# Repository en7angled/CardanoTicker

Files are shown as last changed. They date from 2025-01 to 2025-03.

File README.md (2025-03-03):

# CardanoTicker

CardanoTicker is an open-source DIY project designed to provide real-time insights into the Cardano blockchain. It features a customizable, user-friendly dashboard with a 3D-printed case for assembly, making it an accessible solution for blockchain enthusiasts and developers alike.

## Project Overview

The CardanoTicker project is a part of Project Catalyst, aiming to explore new use cases for the Cardano ecosystem. With a focus on modularity and accessibility.

## Features

- **Open Source**: Fully customizable; contributions are welcome via GitHub.
- **Flexible Design**: Supports various display configurations, including static and dynamic displays.
- **Low-Power Option**: Alternative build using ESP32/Raspberry Pi Pico for energy-efficient operation.
- **Customizable Dashboards**: Three pre-configured dashboards for price, blockchain, and node data.

## Getting Started

Follow these steps to assemble and configure your CardanoTicker:

### 1. Hardware Components

Refer to the [Hardware Components List](https://github.com/en7angled/CardanoTicker/blob/main/m1/hardware_components_list.md) for detailed sourcing options. All components are listed with suppliers, costs, and compatibility information.

### 2. Software Setup

Clone the repository and follow the Setup Guide to configure the software:
- [Connected Version (raspberry pi)](https://github.com/en7angled/CardanoTicker/blob/main/docs/installation_guide_raspberry_pi.md) 
- [Wireless Version (esp32)](https://github.com/en7angled/CardanoTicker/blob/main/docs/installation_guide_esp32.md) 

### 3. System Components Overview

Refer to the [System Components](https://github.com/en7angled/CardanoTicker/blob/main/docs/System_Components.md) for the system design details

### 4. 3D Case Printing

Download the STL files from the [Printables link](https://www.printables.com/model/1145410-4-inch-display-case). Ensure you have access to a 3D printer and follow the printing instructions for optimal results.

## Screenshots


## Contribution Guidelines

We welcome contributions from the community! Here’s how you can contribute:

1. Report bugs or suggest features via [GitHub Issues](https://github.com/en7angled/CardanoTicker/issues).
2. Discuss ideas in the [GitHub Discussions](https://github.com/en7angled/CardanoTicker/discussions/).
3. Submit pull requests (PRs) that align with the project’s goals.

### Future Milestones

- Improved software functionality.
- Enhanced case designs.
- Expanded dashboard capabilities.

## Feedback and Support

Your feedback is invaluable! Use the following channels for support or feedback:

- **GitHub Issues**: [Report Bugs](https://github.com/en7angled/CardanoTicker/issues)
- **Community Discussions**: [Join the Conversation](https://github.com/en7angled/CardanoTicker/discussions/)

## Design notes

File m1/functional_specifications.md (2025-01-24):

# Functional Specifications for Cardano Ticker Project

---

## 1. Overview
The Cardano Ticker project provides a compact, DIY cryptocurrency tracking device displaying real-time data on the Cardano blockchain. It combines low-cost hardware with an easy-to-assemble 3D-printed case and intuitive software dashboards for monitoring critical metrics.

---

## 2. Key Features
1. **Dynamic Data Display:**
   - Real-time price updates for ADA (Cardano).
   - Network statistics, including staking metrics and node status.
   - Blockchain synchronization progress.

2. **Multiple Display Options:**
   - Static e-paper display for low-power builds.
   - Dynamic LCD display for higher refresh rates.

3. **Wireless Connectivity:**
   - Wi-Fi-enabled updates for data fetching.
   - Optional battery-powered operation for portable setups.

4. **Open-Source and Expandable:**
   - Hosted on GitHub with community contributions encouraged.
   - Flexible software framework allowing feature expansions.

---

## 3. Hardware Requirements
1. **Raspberry Pi Zero 2W or ESP32 (alternative low-power version)**
2. **Display Modules:**
   - E-paper (Waveshare 4.01-inch) or LCD display.
3. **Power Options:**
   - USB charger for non-portable versions.
   - Battery pack for portable versions.
4. **3D-printed Case:**
   - Snap-fit or sliding mechanism for easy assembly.
   - Compatible with common 3D printer formats (STL, OBJ).
5. **MicroSD card**
   - only required for non-portable standalone version
8. **Buttons and Sensors (Optional):**
   - For user interactions or future extensions.

---

## 4. Software Functionalities
### 4.1 Data Fetching Module
- Periodically fetches data from Cardano blockchain APIs.
- Includes caching to handle network interruptions.

### 4.2 Display Management Module
- Dynamically updates screens based on the selected display type.
- Allows switching between dashboards (price, node, blockchain).

### 4.3 Configuration Module
- Provides initial setup through a web interface or USB configuration file.
- Allows customization of update intervals and data sources.

### 4.4 Dashboard Mock-ups
#### 1. Price Information Dashboard:
- Displays current ADA price in multiple currencies.
- Includes percentage change and price trends.

#### 2. Blockchain Dashboard:
- Shows network status, slot height, and block progress.
- Displays epoch and slot details.

#### 3. Node Dashboard:
- Provides node synchronization status.
- Displays peer connections and uptime.

---

## 5. Data Sources
- **API Integrations:**
  - BlockFrostApi or CryptoCompare for price updates.
  - BlockFrostApi, Cardano Explorer APIs for network statistics.
  - Easy to integrate other API providers and data sources
- **Fallback Mechanisms:**
  - Local cache for offline scenarios.
---

## 6. Compatibility
- **Operating System Support:**
  - Raspberry Pi OS (Lite or Full).
  - ESP-IDF (for ESP32 builds).
- **File Formats:**
  - STL, OBJ, 3MF for 3D printing.
- **Connectivity:**
  - Wi-Fi or USB for updates.

---

## 7. Testing and Validation
- **Hardware Tests:**
  - Fit and alignment of 3D-printed components.
  - Functionality tests for all hardware modules.
- **Software Tests:**
  - API response validation.
  - Display refresh tests.
---

## 8. User Feedback Mechanisms
1. GitHub Issues for reporting bugs.
2. Pull requests for community contributions.

---

## 9. Deployment and Delivery
- **GitHub Repository:**
  - Hosting code, documentation, and 3D files.
- **Thingiverse/Printables:**
  - STL files for 3D printing.
- **Documentation:**
  - Step-by-step assembly and configuration guides.

---

## 10. Future Roadmap
1. Integration with additional blockchains.
2. Enhanced data visualization tools.
3. Battery optimization for longer runtimes.

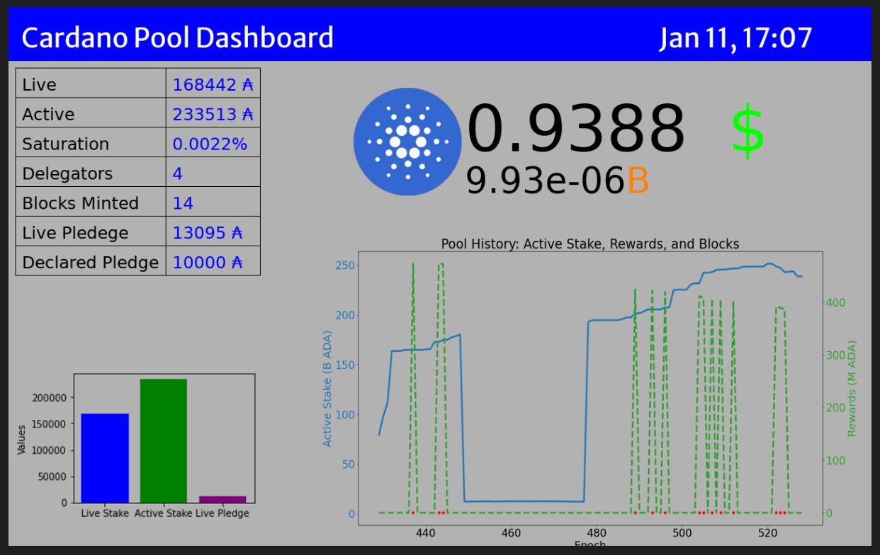
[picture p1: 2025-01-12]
m1/dashboard_mockups/pool_dashboard/pool_simple_with_price.jpeg

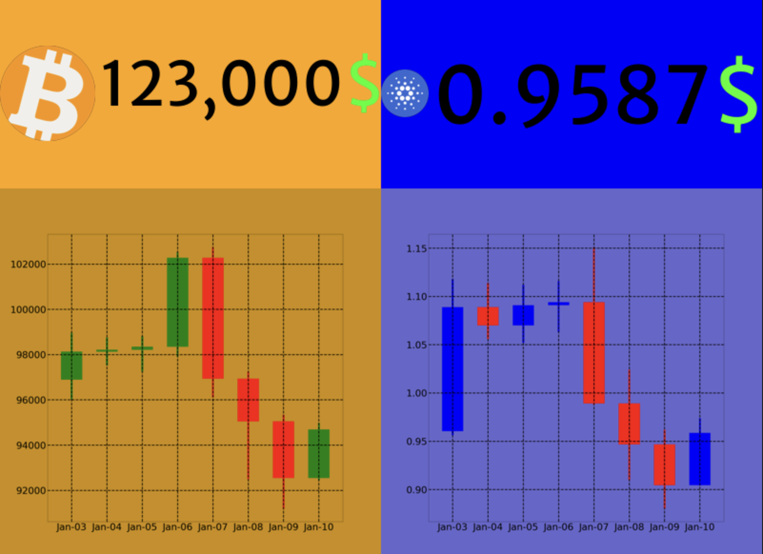
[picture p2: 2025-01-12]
m1/dashboard_mockups/price_dashboard/ada_btc_usd_live_chart.png

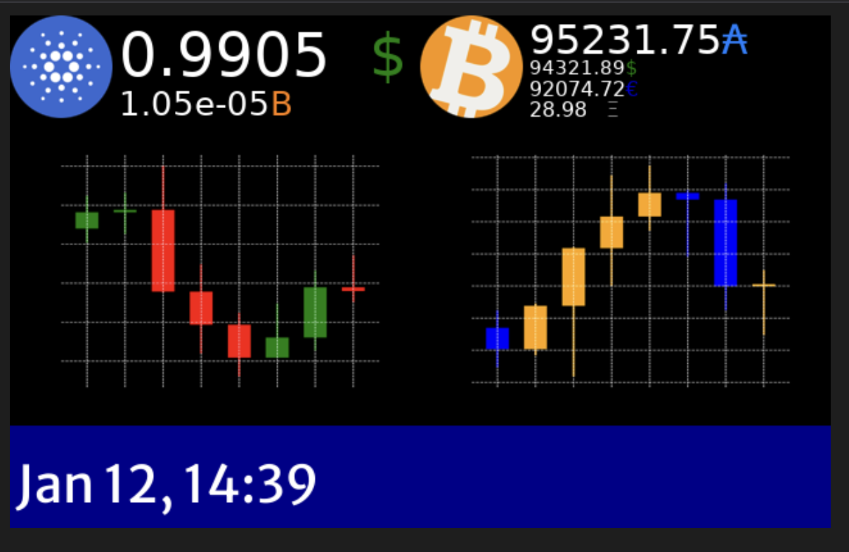
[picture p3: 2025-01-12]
m1/dashboard_mockups/price_dashboard/ada_btc_ticker_dark.png

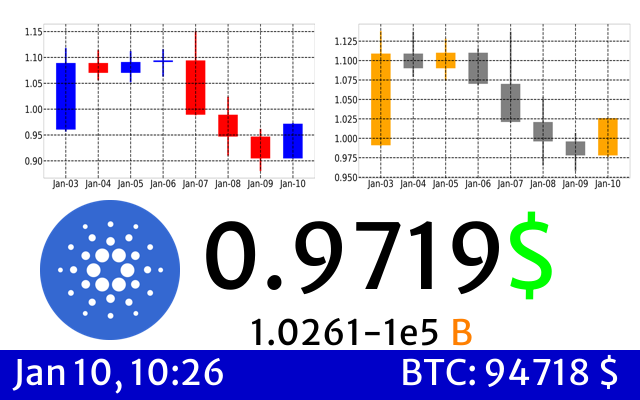
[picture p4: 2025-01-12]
m1/dashboard_mockups/price_dashboard/ada_btc_ticker.bmp

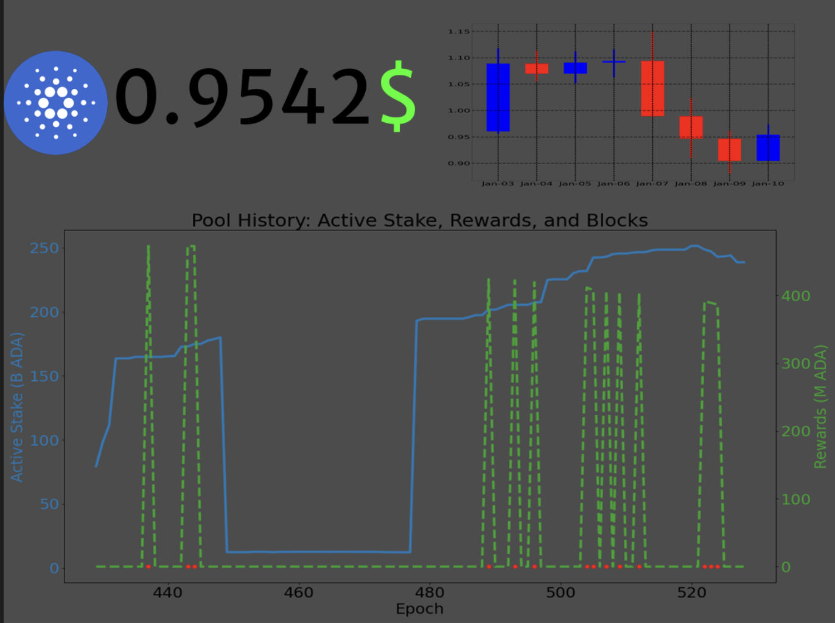
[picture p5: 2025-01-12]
m1/dashboard_mockups/pool_dashboard/pool_and_price_chart.png

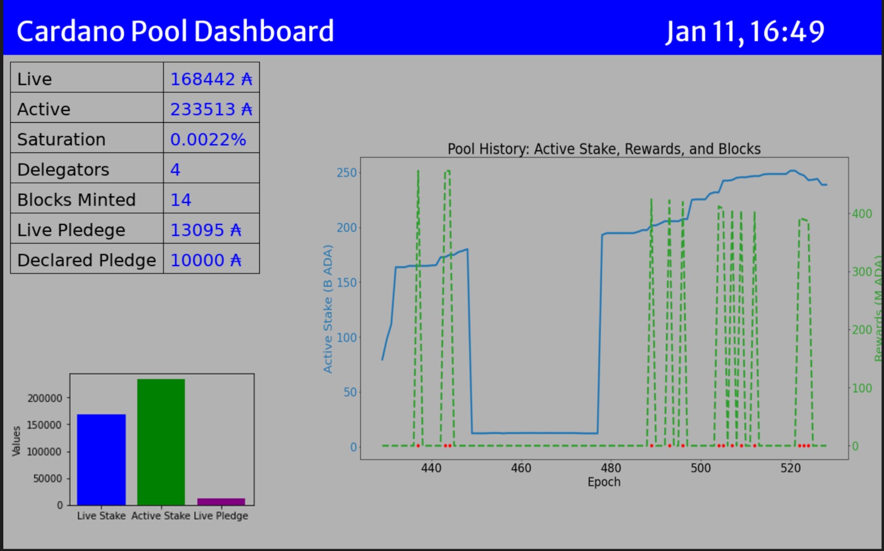
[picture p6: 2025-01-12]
m1/dashboard_mockups/pool_dashboard/pool_simple.jpeg

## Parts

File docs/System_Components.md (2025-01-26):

# CardanoTicker Software Components Architecture

## Overview
The **CardanoTicker** integrates hardware and software to display blockchain data on e-ink or LCD screens. Its architecture is designed for modularity, enabling dynamic updates and user interaction via buttons.

## Software Components

### 1. Config Manager
- **Role**: Manages and provides configuration settings.
- **Data Flow**: Interacts with other components to supply necessary configurations.

### 2. Data Fetcher
- **Role**: Fetches and processes data from blockchain APIs.
- **Data Flow**: Supplies parsed data to the Dashboard Generator.

### 3. Dashboard Generator
- **Role**: Combines data, configuration, and a dashboard description file to generate and update the final dashboard image.
- **Data Flow**:
  - Receives configuration from Config Manager.
  - Retrieves data from Data Fetcher.
  - Uses a dashboard description file containing widget types and layout positions to generate the final dashboard.

### 4. Display
- **Role**: Renders visual content for the user.
- **Data Flow**: Receives the final dashboard image from the Dashboard Generator.

### 5. Buttons
- **Role**: Provides interactivity via user input.
- **Data Flow**: Triggers actions in Config Manager and Dashboard Generator.

## Runners

The system operates with two primary runners to handle distinct tasks:

### 1. Provider
- **Purpose**: Acts as the backend service to fetch blockchain data, process it, and prepare it for display.
- **Responsibilities**:
  - Fetches data via APIs using the `Data Fetcher`.
  - Passes data to the `Dashboard Generator` for processing.
- **Execution**:
  - In connected versions, runs on the same device as the Displayer.
  - In wireless versions, runs on a separate machine on the same network.

### 2. Displayer
- **Purpose**: Manages the rendering and user-facing operations of the CardanoTicker.
- **Responsibilities**:
  - Utilizes the `Dashboard Generator` to create the final dashboard image.
  - Sends the image to the `Display` for rendering.
  - Handles user input from the `Buttons` to interact with dashboards.
- **Execution**:
  - Runs on the device connected to the e-ink or LCD display.

## Data Flow Diagram 
```mermaid
graph TD
    subgraph Provider
        ConfigManager[Config Manager] -->|Provides Config| DataFetcher[Data Fetcher]
        DataFetcher -->|Supplies Data| DashboardGenerator[Dashboard Generator]
        DashboardDescription[Dashboard Description File] -->|Defines Layout| DashboardGenerator
    end

    subgraph Displayer
        DashboardGenerator -->|Generates Final Image| Display[Display]
        Buttons -->|Triggers Actions| DashboardGenerator
    end
```

## Wireless vs Connected Architecture

### Connected Version
- Both the Provider and Displayer run on the same device.
- Suitable for setups using Raspberry Pi or similar hardware.

### Wireless Version
- The Provider runs on a separate machine (e.g., a server or PC) connected via the same network.
- The Displayer runs on the ESP32 or similar low-power device, fetching processed data from the Provider.

```mermaid
graph TD
    subgraph Wireless_Provider
        ConfigManager[Config Manager] -->|Provides Config| DataFetcher[Data Fetcher]
        DataFetcher -->|Supplies Data| DashboardGenerator[Dashboard Generator]
        DashboardDescription[Dashboard Description File] -->|Defines Layout| DashboardGenerator
        DashboardGenerator -->|Generates| Image[Final Image Frame]
    end

    subgraph Wireless_Displayer
        ESP32[ESP32 Device] -->|Fetches Image| Image
        ESP32 -->|Displays| Display[Display]
        ESP32 -->|Receives Input| Buttons
    end

    Wireless_Provider -->|Transfers Data| Wireless_Displayer
```

## Summary
The CardanoTicker architecture is modular and extensible, enabling easy updates, efficient data handling, and user-friendly interaction through a clear component flow. The two main runners, the Provider and the Displayer, ensure seamless backend and frontend operations. The `Dashboard Generator` plays a central role, utilizing a dashboard description file to define widget types and layout positions, ensuring flexibility and customization. For connected versions, both runners operate on the same device. In wireless versions, the Provider and Displayer communicate over the network, enhancing flexibility for distributed setups.

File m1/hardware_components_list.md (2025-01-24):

# Hardware Components List

## 1. Connected Static Display
**Description:** This build uses a Raspberry Pi Zero 2 W as the main controller and features a static e-paper display for low-power, high-visibility output. It connects directly to a power source and is ideal for setups that do not require wireless functionality.
| Component | Description | Estimated Cost (USD) | Sourcing Options | Notes |
|---|---|---|---|---|
| 3D Case (Custom Design) | Protective enclosure for hardware. | 0 | resources/case_models/waveshare_4.01| Custom-designed enclosure for the hardware components. Printable with standard 3D printers; files available in STL or OBJ format.  |
| GPIO Header | For connecting displays to the Raspberry Pi. | $1 - $2 | 1. [Adafruit](https://www.adafruit.com/product/3662)<br>2. [SparkFun](https://www.sparkfun.com/raspberry-pi-gpio-male-header-2x20.html)  <br>3. [Mouser Electronics](https://eu.mouser.com/ProductDetail/SparkFun/PRT-14275?qs=YCa/AAYMW01SLG/RsDUFug%3D%3D) | Required for connecting external devices like displays or sensors via GPIO pins. Preinstalled headers simplify setup, but unsoldered options allow custom configurations. Supports SPI, I2C, and UART communication protocols. |
| Push Button (x2) | Momentary push buttons for user interaction. | $1 - $3 each | 1. [Adafruit]( https://www.adafruit.com/product/1010)<br>2. [SparkFun](https://www.sparkfun.com/products/97)<br>3. [Amazon](https://www.amazon.com/DIYables-Button-Arduino-ESP8266-Raspberry/dp/B0BXKN4TY6) | SPST (Single Pole Single Throw) push buttons are recommended. Ensure 3.3V or 5V compatibility. |
| E-paper color display | E-paper slow refresh rate with color support | $30 - $40 | 1. [Waveshare](https://www.waveshare.com/4.01inch-e-paper-hat-f.htm)  <br>2. [Waveshare](https://www.waveshare.com/4inch-e-paper-hat-plus-e.htm)<br>3. [GoodDisplay](https://www.good-display.com/product/532.html)<br>4. [Spotpear](https://spotpear.com/shop/Raspberry-Pi-Jetson-Nano-Arduino-STM32-4-inch-e-Paper-Ink-Spectra-E6-600x400-Screen-Display/4inch-e-Paper-E.html) | Low-power e-paper display with colors. The refresh rate is ~15s which makes it suitable for updating the data once at ~30 minutes to avoid the chance of glazing at the ticker during the refresh. Compatible with both Raspberry Pi and ESP32 via SPI interface.|
| Raspberry Pi Zero 2 W | Single-board computer for running software components. | $15 | 1. [Raspberry Pi Official Store](https://www.raspberrypi.com/products/raspberry-pi-zero-2-w/)  <br>2. [Amazon](https://www.amazon.co.uk/Raspberry-Pi-Zero-2-W/dp/B09KLVX4RT)  <br>3. [The Pi Hut](https://thepihut.com/products/raspberry-pi-zero-2) | Compact single-board computer suitable for Linux-based systems. Supports GPIO interface for direct hardware connections. Requires a 5V/2.5A power supply for stable operation. Ensure GPIO header is preinstalled or solder it if necessary. Compatible with HDMI and SPI displays. |
| Micro SD Card (16GB or higher) | Storage for operating system and software. | $5 - $15 | [Amazon](https://www.amazon.de/-/en/Kingston-Industrial-microSD-microSDHC-Adapter/dp/B09CYDWS4J)<br>[Adafruit](https://www.adafruit.com/product/2693)<br>[Best Buy](https://www.bestbuy.com/site/sandisk-ultra-plus-32gb-microsdhc-uhs-i-memory-card/6346822.p?skuId=6346822) | Class 10 or higher recommended for faster performance. |
| **Total Estimated Cost** | | **$55 - $75** | | |

## 2. Connected Dynamic Display
**Description:** This build utilizes a Raspberry Pi Zero 2 W and a dynamic display, making it suitable for applications requiring faster refresh rates. It supports direct connections via HDMI, providing high-quality visuals and responsiveness. It is designed for users who need wired reliability and higher interactivity.

| Component | Description | Estimated Cost (USD) | Sourcing Options | Notes |
|---|---|---|---|---|
| 3D Case (Custom Design) | Protective enclosure for hardware. | 0 | resources/case_models/waveshare_4.01 | Custom-designed enclosure for the hardware components. Printable with standard 3D printers; files available in STL or OBJ format.  |
| GPIO Header | For connecting displays to the Raspberry Pi. | $1 - $2 | 1. [Adafruit](https://www.adafruit.com/product/3662)<br>2. [SparkFun](https://www.sparkfun.com/raspberry-pi-gpio-male-header-2x20.html)  <br>3. [Mouser Electronics](https://eu.mouser.com/ProductDetail/SparkFun/PRT-14275?qs=YCa/AAYMW01SLG/RsDUFug%3D%3D) | Required for connecting external devices like displays or sensors via GPIO pins. Preinstalled headers simplify setup, but unsoldered options allow custom configurations. Supports SPI, I2C, and UART communication protocols. |
| Push Button (x2) | Momentary push buttons for user interaction. | $1 - $3 each | 1. [Adafruit]( https://www.adafruit.com/product/1010)<br>2.[SparkFun](https://www.sparkfun.com/products/97)<br>3. [Amazon](https://www.amazon.com/DIYables-Button-Arduino-ESP8266-Raspberry/dp/B0BXKN4TY6) | SPST (Single Pole Single Throw) push buttons are recommended. Ensure 3.3V or 5V compatibility. |
| Charger and Cable (Optional) | Power adapter and USB cable for non-battery builds. | $5 - $10 | 1. [Raspberry Pi Store](https://www.raspberrypi.com/products/micro-usb-power-supply/)  <br>2. [Amazon](https://www.amazon.de/s?k=Charger+and+Cable&crid=2GIHABL4PKSZU)  <br>3. Local Electronics Stores | Micro USB power adapter providing 5V/2.5A output, suitable for Raspberry Pi Zero 2 W. Ensure compatibility with regional power sockets. USB cables should be high-quality to avoid voltage drops during operation. |
| Raspberry Pi Zero 2 W | Single-board computer for running software components. | $15 | 1. [Raspberry Pi Official Store](https://www.raspberrypi.com/products/raspberry-pi-zero-2-w/)  <br>2. [Amazon](https://www.amazon.co.uk/Raspberry-Pi-Zero-2-W/dp/B09KLVX4RT)  <br>3. [The Pi Hut](https://thepihut.com/products/raspberry-pi-zero-2) | Compact single-board computer suitable for Linux-based systems. Supports GPIO interface for direct hardware connections. Requires a 5V/2.5A power supply for stable operation. Ensure GPIO header is preinstalled or solder it if necessary. Compatible with HDMI and SPI displays. |
| Mini HDMI to HDMI Adapter | Adapter to connect Raspberry Pi Zero 2 W to LCD display via HDMI. | $5 - $10 | 1. [Amazon](https://www.amazon.de/-/en/VIEVRE-Adapter-Gold-Plated-1080p-Black-2-pieces-mini-HDMI/dp/B0CLZQFKB1) | Required for connecting Raspberry Pi Zero 2 W to HDMI-compatible LCD display. |
| Display Options |  E-paper / LCD screen | $20 - $60 | 1. Higher Refresh Rate E-paper (b&w, fast refresh)<br>[Good Display](https://www.good-display.com/product/613.html)<br>[Amazon UK](https://www.amazon.co.uk/Waveshare-HAT-Resolution-Electronic-Controller/dp/B075R4QY3L)<br>[Waveshare](https://www.waveshare.com/5.83inch-e-paper-hat.htm)<br> 2. LCD Screen (high resolution, dynamic display)<br>[Waveshare](https://www.waveshare.com](https://www.waveshare.com/product/displays/lcd-oled/lcd-oled-1/5inch-lcd-for-pi.htm))<br>[Amazon](https://www.amazon.com/HDMI-LCD-Resolution-Resistive-Screen/dp/B07P5H2315)<br> [Emag](https://www.emag.ro/display-pentru-raspberry-pi-waveshare-ips-4-800x480-cu-panou-tactil-4inchhdmilcdwaveshare12030/pd/D8MF35MBM/) |1. Faster e-paper display for dynamic content. Supports SPI; compatible with both Raspberry Pi and ESP32. This can be used for more dynamic content but by giving up colors <br> 2.HDMI-based high refresh rate display for detailed visuals. Compatible with Raspberry Pi using HDMI interface. Not directly compatible with ESP32 without an HDMI driver board, making it impractical for wireless builds. Touchscreen models may require extra drivers and calibration. |
| Micro SD Card (16GB or higher) | Storage for operating system and software. | $5 - $15 | [Amazon](https://www.amazon.de/-/en/Kingston-Industrial-microSD-microSDHC-Adapter/dp/B09CYDWS4J)<br>[Adafruit](https://www.adafruit.com/product/2693)<br>[Best Buy](https://www.bestbuy.com/site/sandisk-ultra-plus-32gb-microsdhc-uhs-i-memory-card/6346822.p?skuId=6346822) | Class 10 or higher recommended for faster performance. |
| **Total Estimated Cost** | | **$60 - $110** | | |

## 3. Wireless Static Display
**Description:** Focused on low-power usage, this build combines an ESP32 WiFi module with a static e-paper display, making it ideal for long runtime battery-powered setups. It is optimized for scenarios where updates are less frequent, offering energy efficiency while maintaining wireless functionality.

| Component | Description | Estimated Cost (USD) | Sourcing Options | Notes |
|---|---|---|---|---|
| 3D Case (Custom Design) | Protective enclosure for hardware. | 0 | resources/case_models/waveshare_4.01 | Custom-designed enclosure for the hardware components. Printable with standard 3D printers; files available in STL or OBJ format.  |
| GPIO Header | For connecting displays to the Raspberry Pi. | $1 - $2 | 1. [Adafruit](https://www.adafruit.com/product/3662)<br>2. [SparkFun](https://www.sparkfun.com/raspberry-pi-gpio-male-header-2x20.html)  <br>3. [Mouser Electronics](https://eu.mouser.com/ProductDetail/SparkFun/PRT-14275?qs=YCa/AAYMW01SLG/RsDUFug%3D%3D) | Required for connecting external devices like displays or sensors via GPIO pins. Preinstalled headers simplify setup, but unsoldered options allow custom configurations. Supports SPI, I2C, and UART communication protocols. |
| Push Button (x2) | Momentary push buttons for user interaction. | $1 - $3 each | 1. [Adafruit]( https://www.adafruit.com/product/1010)<br>2. [SparkFun](https://www.sparkfun.com/products/97)<br>3. [Amazon](https://www.amazon.com/DIYables-Button-Arduino-ESP8266-Raspberry/dp/B0BXKN4TY6) | SPST (Single Pole Single Throw) push buttons are recommended. Ensure 3.3V or 5V compatibility. |
| E-paper color display |  E-paper slow refresh rate with color support | $30 - $40 | 1. [Waveshare](https://www.waveshare.com/4.01inch-e-paper-hat-f.htm)  <br>2. [Waveshare](https://www.waveshare.com/4inch-e-paper-hat-plus-e.htm)<br>3. [GoodDisplay](https://www.good-display.com/product/532.html)<br>4. [Spotpear](https://spotpear.com/shop/Raspberry-Pi-Jetson-Nano-Arduino-STM32-4-inch-e-Paper-Ink-Spectra-E6-600x400-Screen-Display/4inch-e-Paper-E.html) | Low-power e-paper display with 7 colors. The refresh rate is ~15s which makes it suitable for updating the data once at ~30 minutes to avoid the chance of glazing at the ticker during the refresh. Compatible with both Raspberry Pi and ESP32 via SPI interface.|
| ESP32 WiFi Module | Low-power microcontroller for battery-powered versions. In this version the data fetching and rendering is done on an external server for minimising power consumption | $5 - $10 | 1. [SparkFun](https://www.sparkfun.com/sparkfun-thing-plus-esp32-s3.html) <br>2. [Amazon](https://www.amazon.co.uk/esp32-module/s?k=esp32+module)  <br>3. [RS Components](https://uk.rs-online.com/web/p/wi-fi-modules/1697594) | Low-power microcontroller with built-in Wi-Fi and Bluetooth. Supports SPI, I2C, UART, and PWM interfaces for peripherals. Can operate on 3.3V directly; no level shifters required. Recommended for wireless, battery-powered setups. Use deep sleep modes for power-efficient operation. |
| Battery  | Power supply for low-power ESP32 version. | $10 - $20 | 1. [Adafruit](https://www.adafruit.com/product/1566)  <br>2. [SparkFun](https://www.sparkfun.com/lithium-ion-battery-pack-10ah-3a-1a-usb-ports.html)  <br>3. Local Electronics Stores | Power supply for ESP32 builds. Li-ion or Li-Po batteries recommended; ensure proper voltage (3.7V or 5V). Consider adding a battery management system (BMS) for safety and charging support. Capacity depends on runtime needs—calculate based on device consumption. |
| **Total Estimated Cost** | | **$50 - $70** | | |

## 4. Wireless Dynamic Display
**Description:** Designed for portability and flexibility, this build uses an ESP32 WiFi module, enabling wireless operation. It features a dynamic display for higher refresh rates and supports both battery-powered and wired configurations. This build is well-suited for applications requiring real-time updates and mobility.

| Component | Description | Estimated Cost (USD) | Sourcing Options | Notes |
|---|---|---|---|---|
| 3D Case (Custom Design) | Protective enclosure for hardware. | 0 | resources/case_models/waveshare_4.01 | Custom-designed enclosure for the hardware components. Printable with standard 3D printers; files available in STL or OBJ format.  |
| GPIO Header | For connecting displays to the Raspberry Pi. | $1 - $2 | 1. [Adafruit](https://www.adafruit.com/product/3662)<br>2. [SparkFun](https://www.sparkfun.com/raspberry-pi-gpio-male-header-2x20.html)  <br>3. [Mouser Electronics](https://eu.mouser.com/ProductDetail/SparkFun/PRT-14275?qs=YCa/AAYMW01SLG/RsDUFug%3D%3D) | Required for connecting external devices like displays or sensors via GPIO pins. Preinstalled headers simplify setup, but unsoldered options allow custom configurations. Supports SPI, I2C, and UART communication protocols. |
| Push Button (x2) | Momentary push buttons for user interaction. | $1 - $3 each | 1. [Adafruit]( https://www.adafruit.com/product/1010)<br>2. [SparkFun](https://www.sparkfun.com/products/97)<br>3. [Amazon](https://www.amazon.com/DIYables-Button-Arduino-ESP8266-Raspberry/dp/B0BXKN4TY6) | SPST (Single Pole Single Throw) push buttons are recommended. Ensure 3.3V or 5V compatibility. |
| Charger and Cable (Optional) | Power adapter and USB cable for non-battery builds. | $5 - $10 | 1. [Raspberry Pi Store](https://www.raspberrypi.com/products/micro-usb-power-supply/)  <br>2. [Amazon](https://www.amazon.de/s?k=Charger+and+Cable&crid=2GIHABL4PKSZU)  <br>3. Local Electronics Stores | Micro USB power adapter providing 5V/2.5A output, suitable for Raspberry Pi Zero 2 W. Ensure compatibility with regional power sockets. USB cables should be high-quality to avoid voltage drops during operation. |
| ESP32 WiFi Module | Low-power microcontroller for battery-powered versions. In this version the data fetching and rendering is done on an external server for minimising power consumption | $5 - $10 | 1. [SparkFun](https://www.sparkfun.com/sparkfun-thing-plus-esp32-s3.html) <br>2. [Amazon](https://www.amazon.co.uk/esp32-module/s?k=esp32+module)  <br>3. [RS Components](https://uk.rs-online.com/web/p/wi-fi-modules/1697594) | Low-power microcontroller with built-in Wi-Fi and Bluetooth. Supports SPI, I2C, UART, and PWM interfaces for peripherals. Can operate on 3.3V directly; no level shifters required. Recommended for wireless, battery-powered setups. Use deep sleep modes for power-efficient operation. |
| Higher Refresh Rate E-paper | Faster e-paper display for dynamic content. Supports SPI; compatible with both Raspberry Pi and ESP32. This can be used for more dynamic content but by giving up colors | $40 - $60 | 1. [Good Display](https://www.good-display.com/product/386.html) <br>2. [Good Display](https://www.good-display.com/product/226.html) <br>3. [Amazon UK](https://www.amazon.co.uk/Waveshare-Module-Resolution-Electronic-Controller/dp/B074NR1SW2) <br> | Faster e-paper display ideal for dynamic content. Supports SPI interface and works with both Raspberry Pi and ESP32. Partial refresh improves update speed compared to standard e-paper displays. Library support includes GxEPD2 for ESP32 and Python libraries for Raspberry Pi. |
| Battery  | Power supply for low-power ESP32 version. | $10 - $20 | 1. [Adafruit](https://www.adafruit.com/product/1566)  <br>2. [SparkFun](https://www.sparkfun.com/lithium-ion-battery-pack-10ah-3a-1a-usb-ports.html)  <br>3. Local Electronics Stores | Power supply for ESP32 builds. Li-ion or Li-Po batteries recommended; ensure proper voltage (3.7V or 5V). Consider adding a battery management system (BMS) for safety and charging support. Capacity depends on runtime needs—calculate based on device consumption. |
| **Total Estimated Cost** | | **$65 - $110** | | |

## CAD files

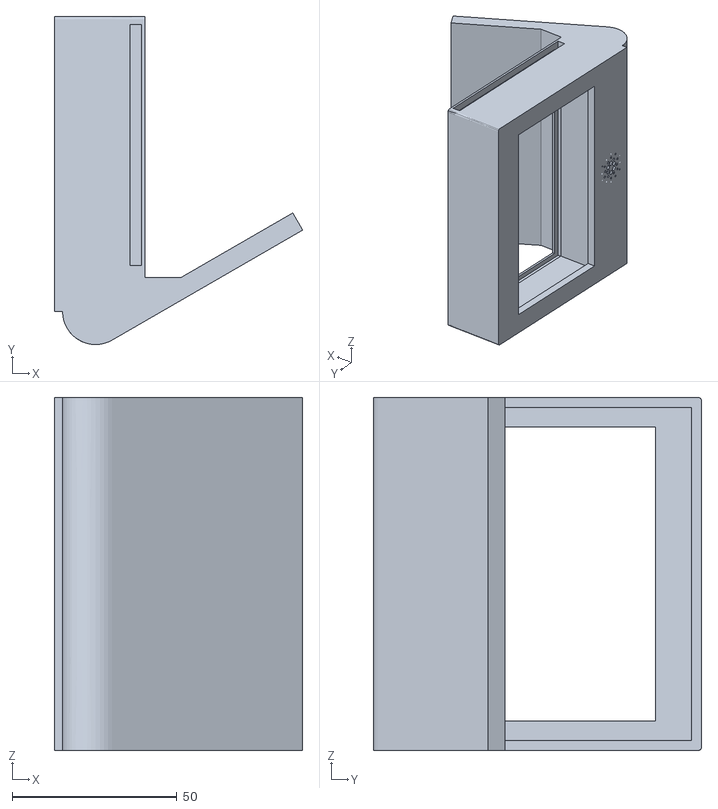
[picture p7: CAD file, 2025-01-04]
src/cardano_ticker/resources/case_models/waveshare_4.01/main_body.stl
75.3 x 99.5 x 107.0

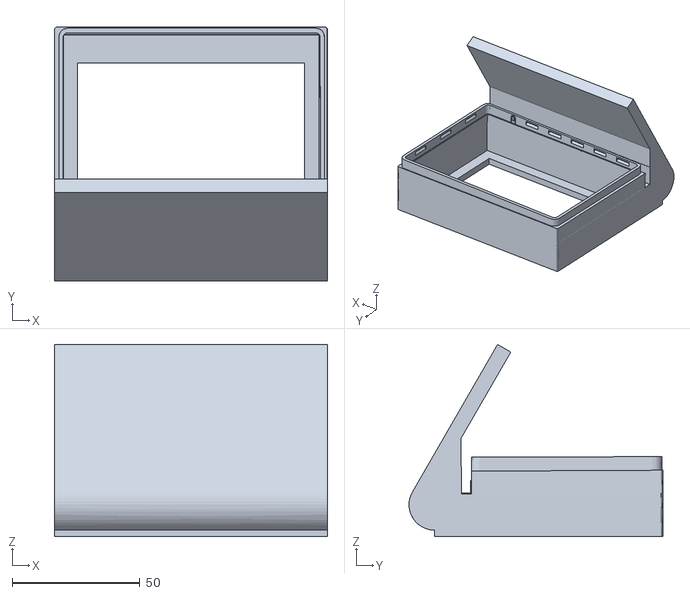
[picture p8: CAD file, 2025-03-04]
resources/case_models/waveshare_4.01/main_frame.stl
107.0 x 99.5 x 75.3

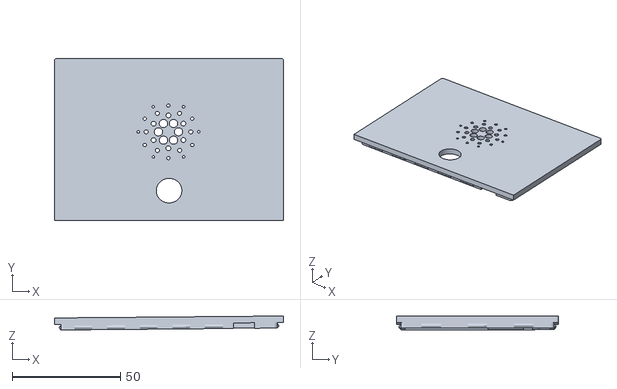
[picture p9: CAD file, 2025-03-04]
resources/case_models/waveshare_4.01/back_lid_v1.stl
106.0 x 75.0 x 6.49

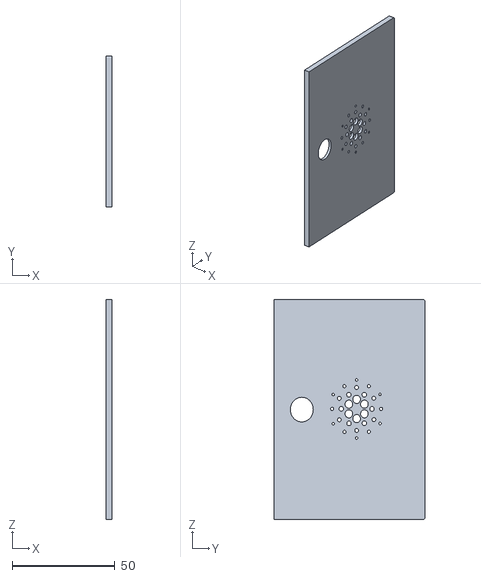
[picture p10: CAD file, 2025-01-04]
src/cardano_ticker/resources/case_models/waveshare_4.01/back_lid.stl
3.00 x 73.5 x 107.0

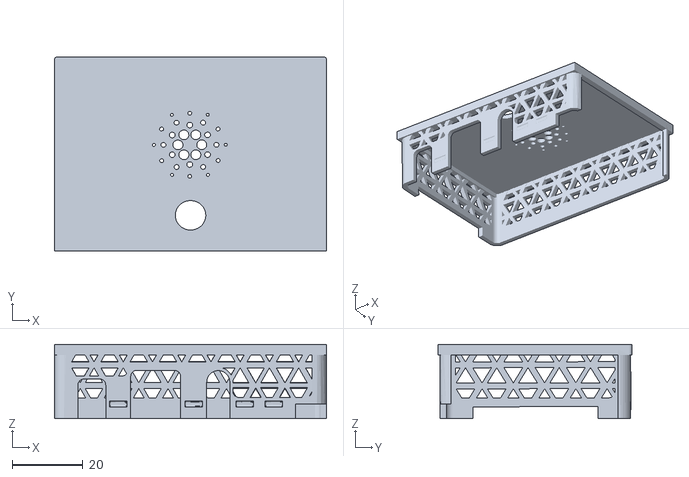
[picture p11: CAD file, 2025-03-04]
resources/case_models/waveshare_4.01/back_lid_v2_2nd_piece.stl
77.0 x 55.0 x 21.0

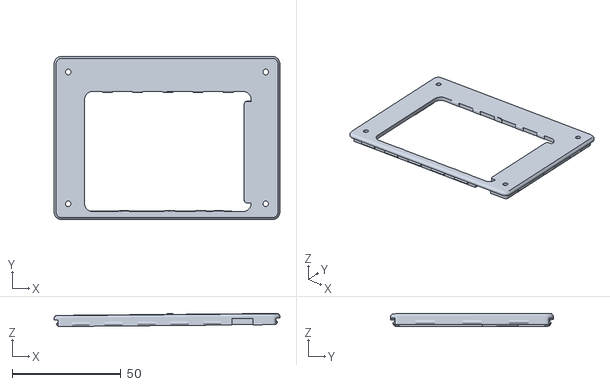
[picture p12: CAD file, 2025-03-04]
resources/case_models/waveshare_4.01/back_lid_v2_1st_piece.stl
104.0 x 75.0 x 6.04

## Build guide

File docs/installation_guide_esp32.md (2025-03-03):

# CardanoTicker Installation Guide for ESP32

## Overview
This guide explains how to install and configure the **CardanoTicker** for the ESP32 version. The system consists of two main components:
1. **Server (Dashboard Provider)** - Runs on a PC to fetch and process blockchain data.
2. **Displayer** - Runs on the ESP32 to render and display the processed data.

## Prerequisites
### Hardware Requirements
- ESP32 microcontroller
- Waveshare e-paper display (or other compatible displays)
- Power supply for ESP32

### Software Requirements
- A PC with Linux/macOS/Windows (for the server)
- ESP32 support installed in **Arduino IDE**
- Required ESP32 libraries (listed below)
- WiFi credentials and server details

## 1. Setting Up the Server (Dashboard Provider)
The server is responsible for fetching blockchain data and generating dashboard images.

### Steps:
1. Clone the repository:
   ```sh
   git clone https://github.com/en7angled/CardanoTicker.git
   cd CardanoTicker
   ```
2. Run the setup script on your PC:
   ```sh
   ./scripts/setup_cardano_ticker_linux.sh
   ```
   This installs dependencies and sets up the server environment.
3. Edit the Configuration File:
  After running the setup script, update the `config.json` file with your Blockfrost API key:
  ```bash
  nano /home/[username]/cardano_ticker_config.json
  ```
  Replace `YOUR_PROJECT_ID` with the API key from [Blockfrost.io](https://blockfrost.io/).
  You can also edit some other settings from the config as you see fit.

- Restart Services After Configuration:**
  ```bash
  sudo systemctl restart cardano-ticker-provider
  ```
  Ensure that the server is running and accessible over the network. 
  The server exposes two different types of the dashboard (color and bw):
  http://127.0.0.1:5335/latest-image and http://127.0.0.1:5335/latest-image-bw

## 2. Setting Up the Displayer (ESP32)
### Steps:
1. Install **Arduino IDE** and add ESP32 board support.
2. Clone the ESP32 displayer code:
   ```sh
   cd CardanoTicker/src/displayers/esp32
   ```
3. Update the **displayer configuration**:
   - Open `displayer/displayer_config.h`
   - Modify the following fields with your network and server details:
     ```cpp
     #define WIFI_SSID "Your_WiFi_SSID"
     #define WIFI_PASSWORD "Your_WiFi_Password"
     #define SERVER_URL "http://your-server-ip:port"
     ```
4. Open **Arduino IDE** and load the project.
5. Install the required libraries:
   - **GFX Library** for rendering
   - **WiFiClient** for network connectivity
6. Compile and upload the code to ESP32.

## 3. Display Compatibility
The ESP32 displayer currently supports Waveshare e-paper displays. If using a different display, implement the `display_handler` interface:
- Path: `src/displayers/esp32/libraries/waveshare`
- Reference implementation: [Waveshare Libraries](https://github.com/en7angled/CardanoTicker/tree/main/src/displayers/esp32/libraries/waveshare)

For more details on Waveshare displays and ESP32 driver boards, refer to:
- [Waveshare ESP32 Driver Board Documentation](https://www.waveshare.com/wiki/E-Paper_ESP32_Driver_Board)

## 4. Pin Mapping for Waveshare E-Paper Displays
| PIN  | ESP32  | Description |
|---|---|---|
| VCC  | 3V3 | Power (3.3V) |
| GND  | GND | Ground |
| DIN  | P14 | SPI MOSI (Data Input) |
| SCLK | P13 | SPI CLK (Clock Input) |
| CS | P15 | Chip Select (Active Low) |
| DC | P27 | Data/Command Select |
| RST  | P26 | Reset (Active Low) |
| BUSY | P25 | Busy Status Output |

## Final Steps
- Ensure both the server and ESP32 displayer are running.
- The ESP32 should successfully fetch and render the dashboard.
- Debugging can be done using the Serial Monitor in **Arduino IDE**.

### Troubleshooting
- **ESP32 not connecting to WiFi?** Check `displayer_config.h` for correct credentials.
- **Dashboard not loading?** Ensure the server is running and accessible.
- **Custom display not supported?** Implement the `display_handler` interface from the [waveshare library](https://github.com/en7angled/CardanoTicker/tree/main/src/displayers/esp32/libraries/waveshare).

---
For further details, visit the [CardanoTicker GitHub Repository](https://github.com/en7angled/CardanoTicker).

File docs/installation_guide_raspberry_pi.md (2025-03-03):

# **Getting Started: Cardano Ticker Installation Guide**

This guide walks you through setting up the Cardano Ticker for the connected version using a Raspberry Pi Zero 2W. The process has been streamlined with setup scripts for easy installation.

---

## **1. Prerequisites**

Before starting, ensure you have the following items:
- Raspberry Pi (3 / 4/ 5 / Zero 2W)
- MicroSD card (16GB or larger, Class 10 or better)
- Power adapter
- Internet connection (Wi-Fi or Ethernet via an adapter)
- Cardano Ticker hardware components (e-paper/lcd display, buttons, etc.)

---

## **2. Raspberry Pi Setup**

1. **Download and Install Raspberry Pi OS:**
   - Download the latest Raspberry Pi OS Lite (recommended for minimal resource usage) from the official Raspberry Pi website.
   - Use Raspberry Pi Imager or balenaEtcher to write the OS image to your MicroSD card.

2. **Boot and Configure the Pi:**
   - Insert the MicroSD card into the Pi and power it on.
   - Follow the setup wizard to configure Wi-Fi, locale, and SSH (optional).

3. **Download the Repository and Setup Scripts:**
   - Clone the entire Cardano Ticker repository to your Pi:
     ```bash
     git clone https://github.com/en7angled/CardanoTicker.git
     cd CardanoTicker
     ```

4. **Run the `setup_pi.sh` Script:**
   - Navigate to the `scripts` directory and execute the `setup_pi.sh` script:
     ```bash
     cd scripts
     chmod +x setup_pi.sh
     ./setup_pi.sh
     ```
   - The script performs the following:
     - Updates system packages.
     - Installs Python, `pip`, and GPIO libraries.
     - Enables the SPI interface.

   After running the script, your Raspberry Pi will be ready for the Cardano Ticker setup.

---

## **3. Cardano Ticker Installation**

1. **Run the `setup_cardano_ticker_pi.sh` Script:**
   - From the `scripts` directory, execute the `setup_cardano_ticker_pi.sh` script:
     ```bash
     chmod +x setup_cardano_ticker_pi.sh
     ./setup_cardano_ticker_pi.sh
     ```

   **Script Features:**
   - **Option to Use Virtual Environment:**
     The script prompts you to choose whether to install dependencies in a `venv` (recommended) or system-wide with `--break-system-packages`.
   - **Provider Setup:**
     - Installs Python dependencies.
     - Copies and configures the `config.json` file.
     - Sets up the `cardano-ticker-provider` systemd service.
   - **Displayer Setup:**
     - Installs dependencies for the Waveshare e-paper display.
     - Sets up the `cardano-ticker-displayer` systemd service.

---

## **4. Configuration**

- **Edit the Configuration File:**
  After running the setup script, update the `config.json` file with your Blockfrost API key:
  ```bash
  nano /home/pi/cardano_ticker_config.json
  ```
  Replace `YOUR_PROJECT_ID` with the API key from [Blockfrost.io](https://blockfrost.io/).

- **Restart Services After Configuration:**
  ```bash
  sudo systemctl restart cardano-ticker-provider
  sudo systemctl restart cardano-ticker-displayer
  ```

---

## **5. Troubleshooting**

- **Service Logs:**
  Check the logs if the services do not start:
  ```bash
  journalctl -u cardano-ticker-provider -f
  journalctl -u cardano-ticker-displayer -f
  ```

- **Verify SPI Interface:**
  Ensure the SPI interface is enabled:
  ```bash
  lsmod | grep spi
  ```

- **Check Internet Connection:**
  Verify that the Pi is connected to the internet to fetch data and install dependencies.

---

## **6. Next Steps**

Once both services are running:
- Assemble the Cardano Ticker hardware using the provided components and 3D-printed case design.
- Verify the display shows real-time Cardano blockchain data.

For updates, additional features, or troubleshooting, visit the [GitHub repository](https://github.com/en7angled/CardanoTicker).

---

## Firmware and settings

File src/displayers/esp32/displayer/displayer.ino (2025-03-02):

#include <WiFi.h>
#include <HTTPClient.h>
#include <display_handler.h> // Generic display interface
#include <displayer_config.h>
#include <image_fetch_decode.h>


 // !!!! Specific display implementation, Replace with your own
#include <epd_4in01f_col.h>


void connectWiFi() {
    Serial.print("Connecting to WiFi...");
    WiFi.begin(WIFI_SSID, WIFI_PASSWORD);
    while (WiFi.status() != WL_CONNECTED) {
        delay(1000);
        Serial.print(".");
    }
    Serial.println(" Connected!");
}


void setup() {
    Serial.begin(115200);
    connectWiFi();

    //print available heap memory
    Serial.println("Initializing display...");
    DisplayHandler* display = new EPD_4IN01F_Displayer(); // Assign specific display instance();

    Serial.println("Display initialising!");
    display->init();

    Serial.println("Clear!");
    display->clear();
    fetchAndDecodeBMP(display, display->getWidth(), display->getHeight());
    display->update();

    Serial.println("Going to deep sleep...");
    esp_sleep_enable_timer_wakeup(600 * 1000000);
    esp_deep_sleep_start();
}

void loop() {}

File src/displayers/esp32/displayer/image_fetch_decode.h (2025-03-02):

#ifndef IMAGE_FETCH_DECODE_H
#define IMAGE_FETCH_DECODE_H

#include <WiFi.h>
#include <HTTPClient.h>
#include <display_handler.h>
#include <displayer_config.h>


void readBMPHeader(WiFiClient *stream, int &bmpWidth, int &bmpHeight, int &bitDepth, int &dataOffset) {
    uint8_t bmpHeader[14];
    stream->readBytes(bmpHeader, 14);
    dataOffset = bmpHeader[10] | (bmpHeader[11] << 8) | (bmpHeader[12] << 16) | (bmpHeader[13] << 24);
    uint8_t bmpHeaderFull[dataOffset - 14];
    stream->readBytes(bmpHeaderFull, dataOffset - 14);

    bmpWidth = bmpHeaderFull[4] | (bmpHeaderFull[5] << 8);
    bmpHeight = bmpHeaderFull[8] | (bmpHeaderFull[9] << 8);
    bitDepth = bmpHeaderFull[14] | (bmpHeaderFull[15] << 8);
}

uint32_t extractColor(uint8_t *rowBuffer, int rowX, int bitDepth) {
    uint32_t color = 0;
    if (bitDepth == 1) {
        int byteIndex = rowX / 8;
        int bitIndex = 7 - (rowX % 8);
        color = !(rowBuffer[byteIndex] & (1 << bitIndex)) ? 0 : 1;
    } else if (bitDepth == 4) {
        int byteIndex = rowX / 2;
        if (rowX % 2 == 0)
            color = (rowBuffer[byteIndex] >> 4) & 0x0F;
        else
            color = rowBuffer[byteIndex] & 0x0F;
    } else if (bitDepth == 8) {
        color = rowBuffer[rowX];

    } else if (bitDepth == 24 || bitDepth == 32) {
        int pixelIndex = rowX * (bitDepth / 8);
        uint8_t bgra[4] = {rowBuffer[pixelIndex], rowBuffer[pixelIndex+1], rowBuffer[pixelIndex+2], rowBuffer[pixelIndex+3]};
        color = *(uint32_t*)bgra;
    }
    return color;
}

void logInfo(int bmpWidth, int bmpHeight, int bitDepth, bool rotate90, int targetWidth, int targetHeight) {
        Serial.println("===== BMP HEADER INFO =====");
        Serial.print("Width: "); Serial.println(bmpWidth);
        Serial.print("Height: "); Serial.println(bmpHeight);
        Serial.print("Bit Depth: "); Serial.println(bitDepth);
        Serial.print("rotate90: "); Serial.println(rotate90 ? "Yes" : "No");
        Serial.print("Target Width: "); Serial.println(targetWidth);
        Serial.print("Target Height: "); Serial.println(targetHeight);
}

void fetchAndDecodeBMP(DisplayHandler* display, int width, int height) {
    HTTPClient http;
    http.begin(SERVER_URL);
    int httpCode = http.GET();

    if (httpCode == HTTP_CODE_OK) {
        WiFiClient *stream = http.getStreamPtr();
        // Read BMP header
       int bmpWidth, bmpHeight, bitDepth, dataOffset;
        readBMPHeader(stream, bmpWidth, bmpHeight, bitDepth, dataOffset);

        bool rotate90 = (bmpWidth > bmpHeight) && (width < height);

        if (rotate90 && !display->supportsRotation()) {
            Serial.println("Error: Display does not support rotation!");
            return;
        }

        if (display->getSupportedBitDepth() < bitDepth) {
            Serial.println("Error: Display does not support the color depth of the image!");
            return;
        }

        // Calculate target width and height
        int targetWidth = rotate90 ? height : width;
        int targetHeight = rotate90 ? width : height;


        logInfo(bmpWidth, bmpHeight, bitDepth, rotate90, targetWidth, targetHeight);

        // Check if the image is too small for the display
        if (bmpWidth < targetWidth || bmpHeight < targetHeight) {
            Serial.println("Error: Image is too small for the display!");
            return;
        }

        int rowSize = ((bmpWidth * bitDepth + 31) / 32) * 4;
        uint8_t *rowBuffer = (uint8_t*) malloc(rowSize);
        if (!rowBuffer) {
            Serial.println("Error: Not enough memory to allocate row buffer!");
            return;
        }

        float scaleX = (float)bmpWidth / targetWidth;
        float scaleY = (float)bmpHeight / targetHeight;
        int lastReadRow = -1;

        for (int y = 0; y < targetHeight; y++) {
            int bmpY = min((int)(y * scaleY), bmpHeight - 1);

            // Skip rows if needed
            for (int rowToSkip = lastReadRow + 1; rowToSkip < bmpY; rowToSkip++) {
                stream->readBytes(rowBuffer, rowSize);
            }

            // Read row
            stream->readBytes(rowBuffer, rowSize);

            for (int x = 0; x < targetWidth; x++) {
                int bmpX = min((int)(x * scaleX), bmpWidth - 1);
                int newX, newY;
                if (rotate90) {
                    newX = y;
                    newY = targetWidth - x - 1;
                } else {
                    newX = x;
                    newY = y;
                }
                uint32_t color = extractColor(rowBuffer, bmpWidth-bmpX, bitDepth);
                display->setPixel(newX, newY, (uint8_t*)&color);
            }
            lastReadRow = bmpY;

        }
        free(rowBuffer);
    } else {
        Serial.print("Failed to fetch image, error: ");
        Serial.println(httpCode);
    }
    http.end();
}

#endif // IMAGE_FETCH_DECODE_H

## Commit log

2025-01-04 add ticker case for default configuration
    [back_lid.stl, main_body.stl]
2025-01-25 restructure and make add support for packaging
    [back_lid.stl, main_body.stl]
2025-01-25 added config file, allow placeholders in dashboards
    [back_lid.stl, main_body.stl]
2025-02-28 add support for esp32 based displayer
2025-03-02 add support for 4in01f waveshare display esp32
2025-03-04 update 3d case
    [back_lid.stl, back_lid_v1.stl, back_lid_v2_1st_piece.stl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]
2025-04-15 modifying the config to point to correct destination of frame output
2026-01-31 Fix critical issues: syntax error, exception handling, exposed API key
    - Fix missing @ decorator on property in w_coin_price.py (was causing import error)
    - Replace bare except clause with specific exceptions (ApiError, KeyError)
    - Use context manager for thread-safe mutex handling
    - Remove exposed Blockfrost API key from config.json (use BLOCKFROST_PROJECT_ID env var)
2026-01-31 Add portfolio allocation and P&L treemap widgets
    New features:
    - AllocationDonutChart: Donut-style pie chart for portfolio allocation
    - TreemapWidget: Treemap visualization for gains/losses heatmap
    - PortfolioDataFetcher: Connect to portfolio-tracker-web API or use manual data
    Widgets support:
    - Manual data via JSON configuration
    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
2026-01-31 feat: add improved portfolio dashboard v2 with summary bar
    - Add PortfolioSummaryWidget showing key metrics:
    - Portfolio value in USD and BTC
    - Current BTC price
    - Total P&L (or 7d performance when available)
    - Add hide_value option to AllocationDonutChart
    - Create portfolio_dashboard_v2.json with cleaner layout
    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
2026-01-31 fix: improve portfolio dashboard layout and e-ink colors
    - Fix color mapping for Waveshare 4.01" 7-color e-ink display
    using exact RGB values from display driver
    - Redesign PortfolioSummaryWidget with 2x2 grid layout and
    auto-adjusting fonts for better readability
    - Simplify AllocationDonutChart to use labels on pie (like PieChartWidget)
    - Add portfolio_dashboard_v3.json with optimized layout
2026-01-31 chore: remove deprecated portfolio dashboard sample files
    - Delete outdated JSON files for portfolio dashboard examples: portfolio_dashboard_example.json, portfolio_dashboard_live.json, and portfolio_dashboard_v2.json.
    - These files are no longer needed as the dashboard has been updated with new configurations and features.
2026-02-01 feat: enhance DateTimeWidget with customizable font size and update dashboard samples
    - Modified DateTimeWidget to accept an optional font size parameter, allowing for better text display control.
    - Updated portfolio dashboard sample JSON files to include a new date_text widget with specified font size and adjusted positions for improved layout.
2026-02-07 feat: add PortfolioValueChart widget and update dashboard samples
    - Introduced a new PortfolioValueChart widget to visualize portfolio value over time with customizable parameters.
    - Added new JSON configuration files for portfolio dashboards, including both dark and light themes, featuring the new PortfolioValueChart alongside existing widgets.
    - Enhanced PortfolioDataFetcher with a method to fetch historical portfolio values for the new chart.
